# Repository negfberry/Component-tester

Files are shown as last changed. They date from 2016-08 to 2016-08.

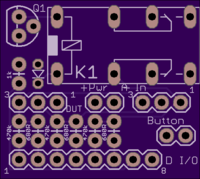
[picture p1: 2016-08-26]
MCT-1601-board-front.png

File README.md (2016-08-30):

# Component-tester
Component tester for Arduino:

For documentation, see the Wiki.

Test many types of semiconductors, resistors, capacitors, inductors, etc.

Full list:

Resistors

Capacitors

Inductors

Diodes

Double diodes - common a/c, series, and inverse-parallel

Zener diodes

BJTs (Bipolar Junction Transistors):

    Regular
  
    Darlington pair
  
FETs:

    JFET
  
    MOSFET:
  
        enhancement mode
    
        depletion mode
    
IGBTs (Insulated Gate Bipolar Transistor)

Triacs

Thyristors

Based on Ardutester and earlier works. Uses the ButtonCtl Arduino library (in my Github). Includes hardware design schematic and PCB layout in Eagle format.
The DUT inputs are relay protected against charged capacitors being inserted.
Do not connect batteries or super capacitors.

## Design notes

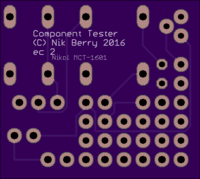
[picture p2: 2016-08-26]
MCT-1601-board-back.png

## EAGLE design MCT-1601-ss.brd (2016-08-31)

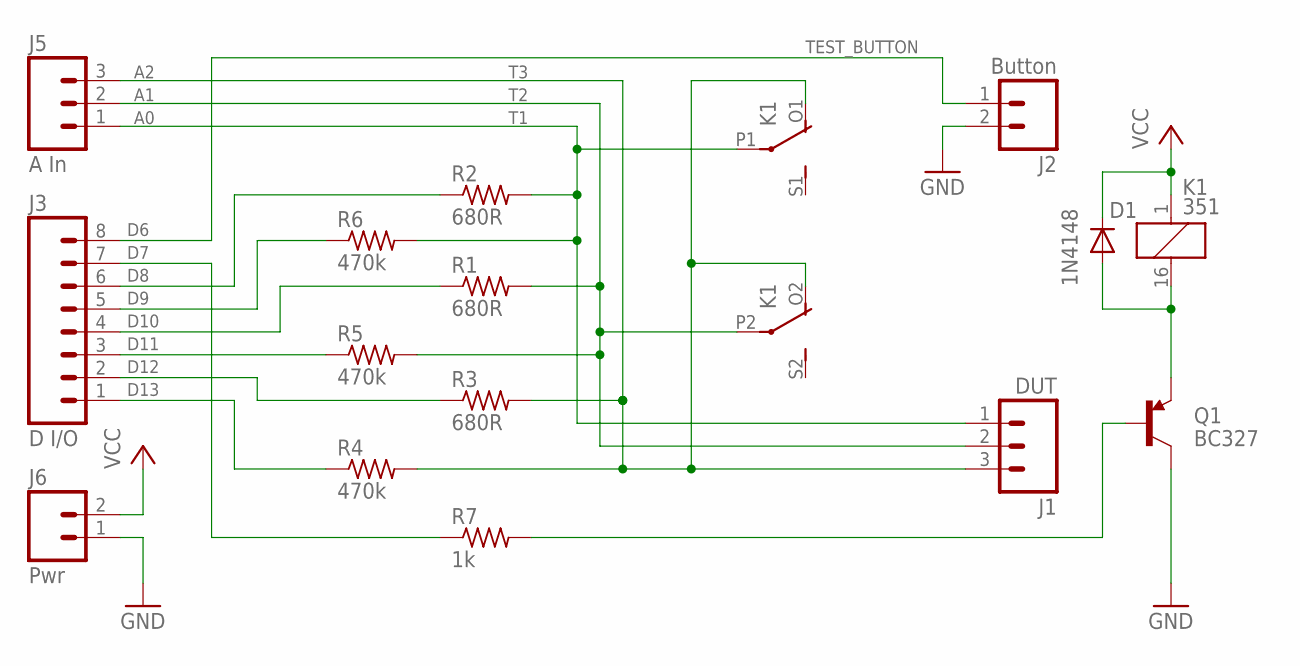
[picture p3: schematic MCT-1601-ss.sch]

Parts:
D1: 1N4148; D-2.5
J1: DUT; 1X03
J2: Button; 1X02
J3: D I/O; 1X08_ROUND
J5: A In; 1X03
J6: Pwr; 1X02
K1: 351
Q1: BC327; TO-92
R1, R2, R3: 680R; 0204/5
R4, R5, R6: 470k; 0204/5
R7: 1k; 0204/5

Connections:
D7: J3.7, R7.1
D8: J3.6, R2.1
D9: J3.5, R6.1
D10: J3.4, R1.1
D11: J3.3, R5.1
D12: J3.2, R3.1
D13: J3.1, R4.1
GND: J2.2, J6.1, Q1.3 (C)
unnamed: Q1.2 (B), R7.2
unnamed: D1.A, K1.16 (2), Q1.1 (E)
T1: J1.1, J5.1, K1.P1, R2.2, R6.2
T2: J1.2, J5.2, K1.P2, R1.2, R5.2
T3: J1.3, J5.3, K1.O1 (O), K1.O2 (O), R3.2, R4.2
TEST_BUTTON: J2.1, J3.8
VCC: D1.C, J6.2, K1.1

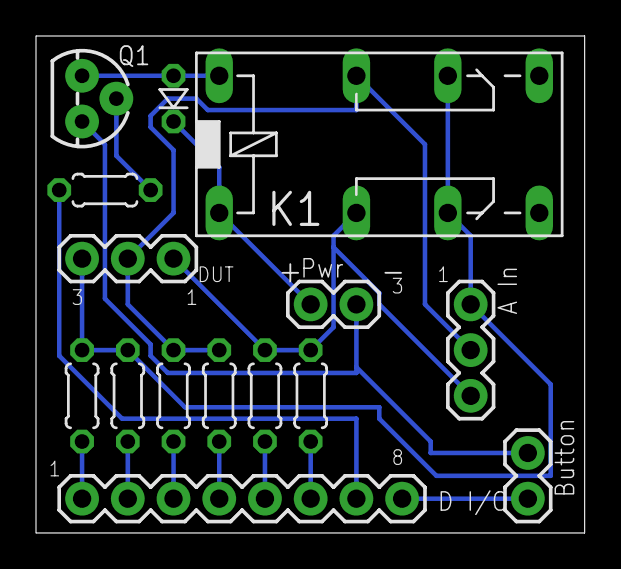
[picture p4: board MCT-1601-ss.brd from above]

Board: 2 copper layers, 30.5 x 27.6 mm, 15 parts (0 on the bottom side), 15 nets.

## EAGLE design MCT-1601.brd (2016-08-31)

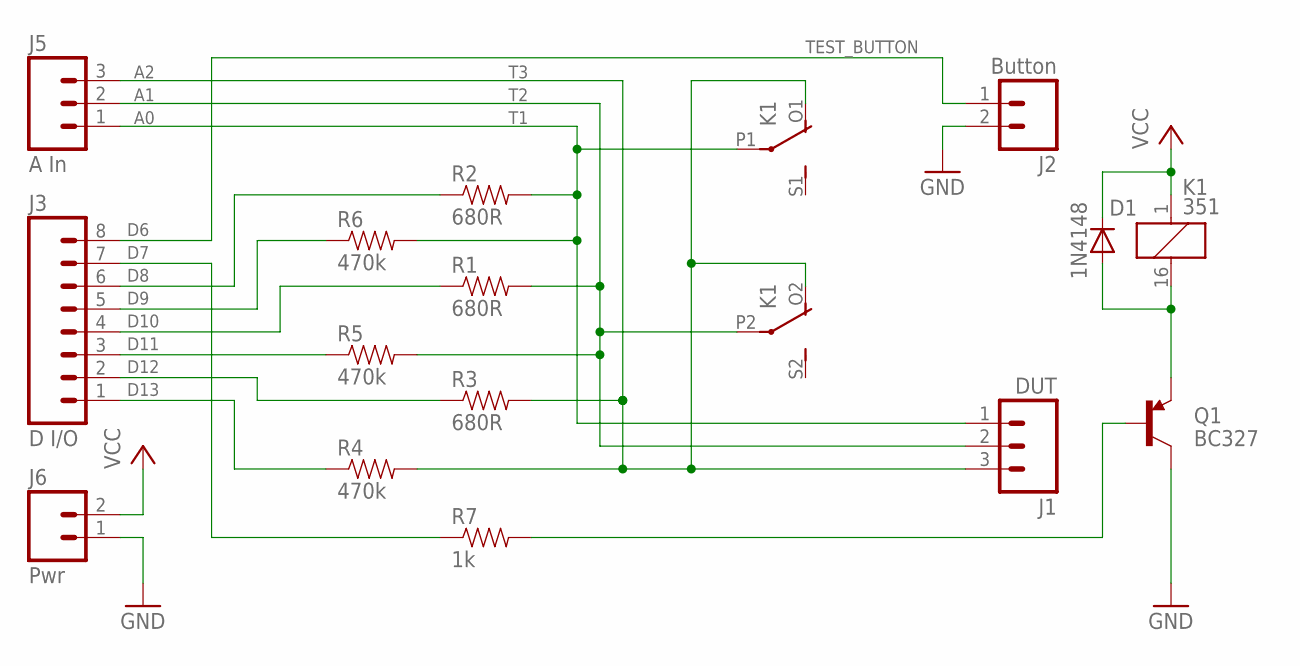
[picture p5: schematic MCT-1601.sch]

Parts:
D1: 1N4148; D-2.5
J1: DUT; 1X03
J2: Button; 1X02
J3: D I/O; 1X08_ROUND
J5: A In; 1X03
J6: Pwr; 1X02
K1: 351
Q1: BC327; TO-92
R1, R2, R3: 680R; AXIAL-0.1
R4, R5, R6: 470k; AXIAL-0.1
R7: 1k; AXIAL-0.1

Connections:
D7: J3.7, R7.P$1 (1)
D8: J3.6, R2.P$1 (1)
D9: J3.5, R6.P$1 (1)
D10: J3.4, R1.P$1 (1)
D11: J3.3, R5.P$1 (1)
D12: J3.2, R3.P$1 (1)
D13: J3.1, R4.P$1 (1)
GND: J2.2, J6.1, Q1.3 (C)
unnamed: Q1.2 (B), R7.P$2 (2)
unnamed: D1.A, K1.16 (2), Q1.1 (E)
T1: J1.1, J5.1, K1.P1, R2.P$2 (2), R6.P$2 (2)
T2: J1.2, J5.2, K1.P2, R1.P$2 (2), R5.P$2 (2)
T3: J1.3, J5.3, K1.O1 (O), K1.O2 (O), R3.P$2 (2), R4.P$2 (2)
TEST_BUTTON: J2.1, J3.8
VCC: D1.C, J6.2, K1.1

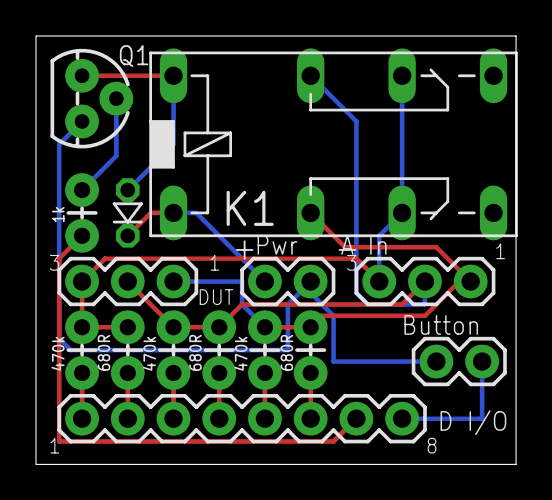
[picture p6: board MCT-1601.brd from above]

Board: 2 copper layers, 26.7 x 23.8 mm, 15 parts (0 on the bottom side), 15 nets.

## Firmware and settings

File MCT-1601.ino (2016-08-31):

#include <EEPROMVar.h>
#include <EEPROMex.h>
#include <ButtonCtl.h>
#include <SoftwareSerial.h>
#include <avr/wdt.h>

/*
 *   _______  .__ __         .__          _____  ____________________      ____  _______________  ____ 
 *  \      \ |__|  | ______ |  |        /     \ \_   ___ \__    ___/     /_   |/  _____/\   _  \/_   |
 *  /   |   \|  |  |/ /  _ \|  |       /  \ /  \/    \  \/ |    |  ______ |   /   __  \ /  /_\  \|   |
 * /    |    \  |    <  <_> )  |__    /    Y    \     \____|    | /_____/ |   \  |__\  \\  \_/   \   |
 * \____|__  /__|__|_ \____/|____/    \____|__  /\______  /|____|         |___|\_____  / \_____  /___|
 *        \/        \/                    \/        \/                           \/        \/     
 *        
 * Original Source from:        http:// www.mikrocontroller.net/articles/AVR-Transistortester
 * Original Software:           by Karl-Heinz Kuebbeler (kh_kuebbeler@web.de)
 *                              The Ardutester software is based on porting by Markus Reschke
 *                              (madires@theca-tabellaria.de) 
 *
 * Ardutester version:          PighiXXX (info@pighixxx.com)
 *
 * This version:                Nik Berry (nikberry@gmail.com)
 * Source/Hardware:             https://github.com/negfberry/Component-tester/
 */

#define VERSION "0.1"
#define EC 13
 
#define DEBUG_PRINT                       // Print on Serial Port

// Button press times in deciseconds (from ButtonCtl library)
#define SEC1_PRESS 10                     // Button Long Press
#define SEC5_PRESS 50                     // Button Unsigned Long Long Press (that's a joke)

// UINT32_MAX
#define UINT32_MAX  ((uint32_t)-1)

// Test probes - Must be an ADC port :-)
#define ADC_PORT PORTC                    // ADC port data register
#define ADC_DDR DDRC                      // ADC port data direction register
#define ADC_PIN PINC                      // Port input pins register
#define TP1 0                             // Test pin 1 (=0)
#define TP2 1                             // Test pin 2 (=1)
#define TP3 2                             // Test pin 3 (=2)
#define R_PORT PORTB                      // Port data register
#define R_DDR DDRB                        // Port data direction register
#define CALIB_BUTTON 4                    // Test/start push button (active low)
#define CONT_BUTTON 5                     // Test/start push button (active low)
#define TEST_BUTTON 6                     // Test/start push button (active low)
#define PROT_RELAY 7                      // Discharge relay (active low)
#define TXPIN 2                           // LCD serial transmit

// ADC voltage reference based on Vcc (in mV).
#define VREF_VCC 5001

//  Offset for the internal bandgap voltage reference (in mV): -100 up to 100
//   - To compensate any difference between real value and measured value.
//   - The ADC has a resolution of about 4.88mV for V_ref = 5V (Vcc) and
//     1.07mV for V_ref = 1.1V (bandgap).
//   - Will be added to measured voltage of bandgap reference.
#define VREF_OFFSET 0

//   Exact values of probe resistors.
//    - Standard value for rLow is 680 Ohms.
//    - Standard value for rHigh is 470k Ohms.

// rLow in Ohms
#define R_LOW 680

// rHigh in Ohms
#define R_HIGH 470000

// Offset for systematic error of resistor measurement with rHigh (470k) in Ohms.
#define RH_OFFSET 700

//   Resistance of probe leads (in 0.01 Ohms).
//    - Resistance of two probe leads in series.
//    - Assuming all probe leads got same/similar resistance.
#define R_ZERO 20

//   Capacitance of the wires between PCB and terminals (in pF).
//   Examples:
//    - 2pF for wires 10cm long
#define CAP_WIRES 15

//   Capacitance of the probe leads connected to the tester (in pF).
//   Examples:
//     capacity  length of probe leads
//     -------------------------------
//      3pF      about 10cm
//      9pF      about 30cm
//     15pF      about 50cm

#define CAP_PROBELEADS 9

// Maximum voltage at which we consider a capacitor being discharged (in mV)
#define CAP_DISCHARGED 2
/*
   Number of ADC samples to perform for each mesurement.
    - Valid values are in the range of 1 - 255.
*/
#define ADC_SAMPLES 50

// Estimated internal resistance of port to GND (in 0.1 Ohms)
#define R_MCU_LOW 200                     // Default: 209

// Estimated internal resistance of port to VCC (in 0.1 Ohms)
#define R_MCU_HIGH 220                    // Default: 235

// Voltage offset of µCs analog comparator (in mV): -50 up to 50
#define COMPARATOR_OFFSET 15

// Capacitance of the probe tracks of the PCB and the µC (in pF)
#define CAP_PCB 42

// Total default capacitance (in pF): max. 255
#define C_ZERO CAP_PCB + CAP_WIRES + CAP_PROBELEADS

// ATMEGA328, 16Mhz Related
#define ADC_CLOCK_DIV (1 << ADPS2) | (1 << ADPS1) | (1 << ADPS0)
#define CPU_FREQ F_CPU
#define OSC_STARTUP 16384

// Component ID's
#define COMP_NONE 0
#define COMP_ERROR 1
#define COMP_RESISTOR 10
#define COMP_CAPACITOR 11
#define COMP_INDUCTOR 12
#define COMP_DIODE 20
#define COMP_BJT 21
#define COMP_FET 22
#define COMP_IGBT 23
#define COMP_TRIAC 24
#define COMP_THYRISTOR 25

// Pre-defined LCD special characters
#define LCD_CHAR_OMEGA 244                // Default: 244
#define LCD_CHAR_MICRO 228


// Error type IDs
#define TYPE_DISCHARGE 1                  // Discharge error

// FET type bit masks (also used for IGBTs)
#define TYPE_N_CHANNEL   B00000001        // N-channel
#define TYPE_P_CHANNEL   B00000010        // P-channel
#define TYPE_ENHANCEMENT B00000100        // Enhancement mode
#define TYPE_DEPLETION   B00001000        // Depletion mode
#define TYPE_MOSFET      B00010000        // MOSFET
#define TYPE_JFET        B00100000        // JFET
#define TYPE_IGBT        B01000000        // IGBT (no FET)

// Mode bitmask
#define MODE_LOW_CURRENT   B00000001      // Low test current
#define MODE_HIGH_CURRENT  B00000010      // High test current
#define MODE_DELAYED_START B00000100      // Delayed start

// BJT (bipolar junction transistor) subtype IDs
#define TYPE_REGULAR 1                     // NPN
#define TYPE_DARLINGTON 2                 // PNP

// BJT (bipolar junction transistor) type IDs
#define TYPE_NPN 1                        // NPN
#define TYPE_PNP 2                        // PNP

// Multiplicator tables
#define TABLE_SMALL_CAP 1
#define TABLE_LARGE_CAP 2
#define TABLE_INDUCTOR 3

// Bit flags for pullProbe()
#define FLAG_PULLDOWN B00000000
#define FLAG_PULLUP   B00000001
#define FLAG_1MS      B00001000
#define FLAG_10MS     B00010000

// EEPROM addresses
#define PARAM_RIL 1
#define PARAM_RIH 3
#define PARAM_RZERO 5
#define PARAM_CAPZERO 7
#define PARAM_REFOFFSET 8
#define PARAM_COMPOFFSET 9
#define PARAM_MAGIC 10
#define ROM_MAGIC B10011010

// Tester modes, offsets and values
typedef struct {
  byte samples;                           // Number of ADC samples
  byte refFlag;                           // Internal control flag for ADC
  unsigned int vBandgap;                  // Voltage of internal bandgap reference (mV)
  unsigned int rIntLow;                   // Internal pin resistance of µC in low mode (0.1 Ohms)
  unsigned int rIntHigh;                  // Internal pin resistance of µC in high mode (0.1 Ohms)
  unsigned int rZero;                     // Resistance of probe leads (2 in series) (0.01 Ohms)
  byte capZero;                           // Capacity zero offset (input + leads) (pF)
  signed char refOffset;                  // Voltage offset of bandgap reference (mV)
  signed char compOffset;                 // Voltage offset of analog comparator (mV)
} Parameters;

// Probes
typedef struct {
  // Probe pins
  byte pin1;                              // Probe-1
  byte pin2;                              // Probe-2
  byte pin3;                              // Probe-3
  // Bit masks for switching probes and test resistors
  byte rLow1Mask;                         // rLow mask for probe-1
  byte rHigh1Mask;                        // rHigh mask for probe-1
  byte rLow2Mask;                         // rLow mask for probe-2
  byte rHigh2Mask;                        // rHigh mask for probe-2
  byte rLow3Mask;                         // rLow mask for probe-3
  byte rHigh3Mask;                        // rHigh mask for probe-3
  byte probe1Adc;                         // ADC mask for probe-1
  byte probe2Adc;                         // ADC mask for probe-2
} Probes;

// Checking/probing
typedef struct {
  byte done;                              // Flag for transistor detection done
  byte found;                             // Component basic type that was found
  byte type;                              // Component specific type
  byte subtype;                           // Component specific subtype
  byte resistors;                         // Number of resistors found
  byte diodes;                            // Number of diodes found
  byte probe;                             // Error: probe pin
  unsigned int v;                         // Error: voltage left in mV
} Checks;

// Resistor
typedef struct {
  byte a;                                 // Probe pin #1
  byte b;                                 // Probe pin #2
  byte scale;                             // Exponent of factor (value * 10^x)
  unsigned long int value;                // Resistance
} Resistors;

// Capacitor
typedef struct {
  byte a;                                 // Probe pin #1
  byte b;                                 // Probe pin #2
  signed char scale;                      // Exponent of factor (value * 10^x)
  unsigned long int value;                // Capacitance incl. zero offset
  unsigned long int raw;                  // Capacitance excl. zero offset
} Capacitors;

// Inductor
typedef struct {
  signed char scale;                      // Exponent of factor (value * 10^x)
  unsigned long int value;                // Inductance
} Inductors;

// Diode
typedef struct {
  byte a;                                 // Probe pin connected to anode
  byte c;                                 // Probe pin connected to cathode
  unsigned int vF;                        // Forward voltage in mV (high current)
  unsigned int vF2;                       // Forward voltage in mV (low current)
} Diodes;

// Bipolar junction transistor
typedef struct {
  byte b;                                 // Probe pin connected to base
  byte c;                                 // Probe pin connected to collector
  byte e;                                 // Probe pin connected to emitter
  unsigned long hFe;                      // Current amplification factor
  unsigned int iCeo;                      // Leakage current (in µA)
} Bjts;

// FET
typedef struct {
  byte g;                                 // Test pin connected to gate
  byte d;                                 // Test pin connected to drain
  byte s;                                 // Test pin connected to source
  unsigned int vTh;                       // Threshold voltage of gate in mV
} Fets;

// Output buffer
char outBuffer[12];

// Configuration
Parameters parameters;                    // Tester modes, offsets and values

// Probing
Probes probes;                            // Test probes
Checks check;                             // Checking/testing

// Components
Resistors resistors[3];                   // Resistors (3 combinations)
Capacitors caps[3];                       // Capacitors (3 combinations)
Diodes diodes[6];                         // Diodes (3 combinations in 2 directions)
Bjts bjt;                                 // Bipolar junction transistor
Fets fet;                                 // FET
Inductors inductor;                       // Inductor


const byte symPara[8]     PROGMEM = { B00010010, B00010010, B00010010, B00010010,
                                      B00010010, B00010010, B00010010, B00000000 };

const byte symProt1[8]    PROGMEM = { B00000000, B00000000, B00000000, B00000000,
                                      B00000000, B00011100, B00000100, B00000100 };

const byte symProt2N[8]   PROGMEM = { B00000100, B00000100, B00000100, B00011111,
                                      B00001110, B00001110, B00000100, B00000100 };

const byte symProt2P[8]   PROGMEM = { B00000100, B00000100, B00000100, B00011111,
                                      B00001110, B00001110, B00000100, B00000100 };

const byte symProt3[8]    PROGMEM = { B00000100, B00000100, B00000100, B00011100,
                                      B00000000, B00000000, B00000000, B00000000 };

const byte symLOW1[8]     PROGMEM = { B00000000, B00000000, B00000000, B00010000,
                                      B00010010, B00010101, B00010101, B00011010 };

const byte symLOW2[8]     PROGMEM = { B00000000, B00000000, B00000000, B00000000,
                                      B00010001, B00010001, B00010101, B00001010 };

const byte symR[8]        PROGMEM = { B00000000, B00000000, B00011000, B00010100,
                                      B00010100, B00011000, B00010100, B00010100 };

const byte symF[8]        PROGMEM = { B00000000, B00000000, B00011100, B00010000,
                                      B00010000, B00011000, B00010000, B00010000 };

const byte symRES1[8]     PROGMEM = { B00000100, B00000100, B00000100, B00000100,
                                      B00011111, B00010001, B00010001, B00010001 };

const byte symRES2[8]     PROGMEM = { B00010001, B00010001, B00010001, B00010001,
                                      B00011111, B00000100, B00000100, B00000100 };

const byte symCAP1[8]     PROGMEM = { B00000000, B00000100, B00000100, B00000100,
                                      B00000100, B00000100, B00011111, B00011111 };
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
void loop() {
  byte test;
  byte isDarlington = 1;

  connectDevice(0);                       // Turn off relay (discharge DUT)
  pinMode(TEST_BUTTON, INPUT_PULLUP);
  // Reset variables
  check.found = COMP_NONE;
  check.type = 0;
  check.done = 0;
  check.diodes = 0;
  check.resistors = 0;
  bjt.hFe = 0;
  bjt.iCeo = 0;
  // Reset hardware
  setAdcHighZ();                          // Set all pins of ADC port as input
  if(!gogohut) {
    lcd_clear();
    lcd.print(F("   Nikol MCT-1601"));
  }
  
  // Internal bandgap reference
  parameters.vBandgap = readVoltage(0x0e, 1); // Dummy read for bandgap stabilization
  parameters.vBandgap = readVoltage(0x0e, 1); // Get voltage of bandgap reference
  parameters.vBandgap += parameters.refOffset; // Add voltage offset
  test = testKey();
  connectDevice(1);                       // Turn on relay (connect DUT to tester)
  if(test == 2) {                         // Long Press
    wdt_disable();                        // Disable watchdog
    calibrateAndSave();                      // Calibrate
    return;
  }  
 // if(!gogohut) lcd_clear();
  if(allProbesShorted() == 3) {           // All probes Shorted
#ifdef DEBUG_PRINT
    Serial.println("Probes shorted. Remove short.");
#endif
    lcd_clear();
    lcd.print(F("  Probes shorted."));
    lcd_setcursor(0, 1);
    lcd.print(F("   Remove short."));
    delay(100);
    return;
  }
  // Display start of probing
  dischargeProbes();
  if(!gogohut) {
    lcd_setcursor(0, 2);
    lcd.print(F("Testing..."));
  }
  if(check.found == COMP_ERROR) {     // Discharge failed
    lcd_setcursor(0, 1);
    lcd.print(F("Fail: Battery?"));
    // Display probe number and remaining voltage
    lcd_setcursor(0, 2);
    lcd_testpin(check.probe);
    lcd.print(F(": "));
    displayValue(check.v, -3, 'V');
    lcd_setcursor(4, 3);
    lcd.print(F("press button"));
    testKey();
    return;
  }
  // Check all 6 combinations of the 3 probes
  check.subtype = 0;
  checkProbes(TP1, TP2, TP3);
  if(check.subtype == TYPE_REGULAR)
    isDarlington = 0;
  check.subtype = 0;
  checkProbes(TP2, TP1, TP3);
  if(check.subtype == TYPE_REGULAR)
    isDarlington = 0;
  check.subtype = 0;
  checkProbes(TP1, TP3, TP2);
  if(check.subtype == TYPE_REGULAR)
    isDarlington = 0;
  check.subtype = 0;
  checkProbes(TP3, TP1, TP2);
  if(check.subtype == TYPE_REGULAR)
    isDarlington = 0;
  check.subtype = 0;
  checkProbes(TP2, TP3, TP1);
  if(check.subtype == TYPE_REGULAR)
    isDarlington = 0;
  check.subtype = 0;
  checkProbes(TP3, TP2, TP1);
  if(check.subtype == TYPE_REGULAR)
    isDarlington = 0;
  if(isDarlington) check.subtype = TYPE_DARLINGTON;
  else check.subtype = TYPE_REGULAR;

  // If component might be a capacitor
  if(check.found == COMP_NONE || check.found == COMP_RESISTOR) {
    // Tell user to be patient with large caps
#ifdef DEBUG_PRINT
    Serial.println();
    Serial.println(F("Testing for cap ..."));
#endif
    if(!gogohut)  {
      lcd_clear_line(2);
      lcd.print(F("Testing for cap ..."));
    }
    // Check all possible combinations
    measureCap(TP3, TP1, 0);
    measureCap(TP3, TP2, 1);
    measureCap(TP2, TP1, 2);
  }
  // Call output function based on component type
#ifdef DEBUG_PRINT
  Serial.print(F("Found: "));
  // Components ID's
  switch (check.found) {
    case COMP_ERROR:
      Serial.println(F("Component Error!"));
      break;

    case COMP_NONE:
      Serial.println(F("No Component!"));
      break;

    case COMP_RESISTOR:
      Serial.println(F("Resistor"));
      break;

    case COMP_CAPACITOR:
      Serial.println(F("Capacitor"));
      break;

    case COMP_INDUCTOR:
      Serial.println(F("Inductor"));
      break;

    case COMP_DIODE:
      Serial.println(F("Diode"));
      break;

    case COMP_BJT:
      Serial.println(F("BJT"));
      break;

    case COMP_FET:
      Serial.println(F("FET"));
      break;

    case COMP_IGBT:
      Serial.println(F("IGBT"));
      break;

    case COMP_TRIAC:
      Serial.println(F("TRIAC"));
      break;

    case COMP_THYRISTOR:
      Serial.println(F("Thyristor"));
      break;
  }
#endif
  lcd_clear();
  switch (check.found) {
    case COMP_ERROR:
      showError();
      break;

    case COMP_DIODE:
      showDiode();
      break;

    case COMP_BJT:
      showBjt();
      break;

    case COMP_FET:
      showFet();
      break;

    case COMP_IGBT:
      showIgbt();
      break;

    case COMP_THYRISTOR:
      showSpecial();
      break;

    case COMP_TRIAC:
      showSpecial();
      break;

    case COMP_RESISTOR:
      showResistor();
      break;

    case COMP_CAPACITOR:
      showCapacitor();
      break;

    default:                              // No component found
      showFail();
  }
  testKey();                              // Let the user read the text
  wdt_disable();                          // Disable watchdog
}

// Set ADC port to HiZ mode
void setAdcHighZ(void) {
  ADC_DDR &= ~(1<<TP1);
  ADC_DDR &= ~(1<<TP2);
  ADC_DDR &= ~(1<<TP3);
}

// Set ADC port low
void setAdcLow(void) {
  ADC_PORT &= ~(1<<TP1);
  ADC_PORT &= ~(1<<TP2);
  ADC_PORT &= ~(1<<TP3);
}

// Setup probes, bitmasks for probes and test resistors
void updateProbes(byte probe1, byte probe2, byte probe3) {
  // DSt probe IDs
  probes.pin1 = probe1;
  probes.pin2 = probe2;
  probes.pin3 = probe3;
  // Setup masks using bitmask tables
  probes.rLow1Mask = rLowTable[probe1];
  probes.rHigh1Mask = probes.rLow1Mask + probes.rLow1Mask;
  probes.probe1Adc = adcTable[probe1];
  probes.rLow2Mask = rLowTable[probe2];
  probes.rHigh2Mask = probes.rLow2Mask + probes.rLow2Mask;
  probes.probe2Adc = adcTable[probe2];
  probes.rLow3Mask = rLowTable[probe3];
  probes.rHigh3Mask = probes.rLow3Mask + probes.rLow3Mask;
}

// Check for a short circuit between two probes
byte shortedProbes(byte probe1, byte probe2) {
  byte flag = 0;                          // Return value
  unsigned int v1;                        // Voltage at probe #1 in mV
  unsigned int v2;                        // Voltage at probe #2 in mV

//   Set up a voltage divider between the two probes:
//    - probe1: rLow pull-up
//    - probe2: rLow pull-down
//    - third probe: HiZ

  R_PORT = rLowTable[probe1];
  R_DDR = rLowTable[probe1] | rLowTable[probe2];
  // Read voltages
  v1 = readVoltage(probe1, 1);
  v2 = readVoltage(probe2, 1);
#ifdef DEBUG_PRINT
//  Serial.println(v1);
//  Serial.println(v2);
#endif

//   We expect both probe voltages to be about the same and
//   to be half of Vcc (allowed difference +/- 30mV).

  if((v1 > VREF_VCC / 2 - 30) && (v1 < VREF_VCC / 2 + 30)
   &&(v2 > VREF_VCC / 2 - 30) && (v2 < VREF_VCC / 2 + 30)) flag = 1;

  // Reset port
  R_DDR = 0;
  return flag;
}

 // Check for a short circuit between all probes
byte allProbesShorted(void) {
  byte s = 0;
  
  // Check all possible combinations
  s = shortedProbes(TP1, TP2);
  s += shortedProbes(TP1, TP3);
  s += shortedProbes(TP2, TP3);
  return s;
}

// Control the DUT relay
byte connectDevice(boolean state) {
  pinMode(PROT_RELAY, OUTPUT);
  if(state) digitalWrite(PROT_RELAY, LOW);
  else digitalWrite(PROT_RELAY, HIGH);
  delay(100);
  return allProbesShorted();
}

// Try to discharge any connected components, e.g. capacitors
// The discharge relay should already have accomplished this,
// the first time it's called, so in that case this is more of
// a test that it worked. Subsequent calls really do something.
void dischargeProbes(void) {
  byte cnt;                               // Loop control
  byte limit = 40;                        // Sliding timeout (2s)
  byte id;                                // Test pin
  byte dischargeMask;                     // Bitmask
  unsigned int vNow;                      // Current voltage
  unsigned int vOld[3];                   // Old voltages

  // Set probes to a save discharge mode (pull-down via rHigh)
  // Set ADC port to HiZ input
  setAdcHighZ();
  setAdcLow();
  // All probe pins: rHigh and rLow pull-down
  R_PORT = 0;
  R_DDR = (2 << (TP1 * 2)) | (2 << (TP2 * 2)) | (2 << (TP3 * 2));
  R_DDR |= (1 << (TP1 * 2)) | (1 << (TP2 * 2)) | (1 << (TP3 * 2));
  // Get voltages
  vOld[0] = readVoltage(TP1, 1);
  vOld[1] = readVoltage(TP2, 1);
  vOld[2] = readVoltage(TP3, 1);
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

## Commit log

2016-08-24 Added Darlinton support, Calibration cleanups, PROGMEM icon fixed
    Added a subtype field to the checks struct, and added subtypes 'TYPE_REGULAR' and 'TYPE_DARLINGTON' for BJTs. Added code to save and display this information.
    Made the Calibration functions much neater. Fixed up button presses when in Calibration mode.
    Fixed the generation of custom character icons from Flash, which was borked.
    [MCT-1601.ino]
2016-08-25 Modified to support autodiagnostics on startup
    [MCT-1601.brd, MCT-1601.sch]
2016-08-25 Pictures of the PCB
2016-08-26 Adding correct ec2 verion
    [MCT-1601.brd, MCT-1601.sch]
2016-08-29 Add Zener diodes
2016-08-29 Added double diode and Zener support
2016-08-30 Added extra diode support
2016-08-30 Fixed and enhanced diode display
    [MCT-1601.ino]
2016-08-30 missing series type in double diode entry
2016-08-31 Slightly larger single-sided version of the PCB
    [MCT-1601-ss.brd, MCT-1601-ss.sch]
2016-08-31 Added diode value
    [MCT-1601.brd, MCT-1601.sch]
2016-08-31 Moved traces to bottom
    [MCT-1601-ss.brd]
2016-08-31 Slightly larger single sided PCB

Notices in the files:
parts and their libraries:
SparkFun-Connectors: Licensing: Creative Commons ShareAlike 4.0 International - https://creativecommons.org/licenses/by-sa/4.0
